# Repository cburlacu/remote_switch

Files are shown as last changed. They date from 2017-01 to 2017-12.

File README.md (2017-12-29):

# About

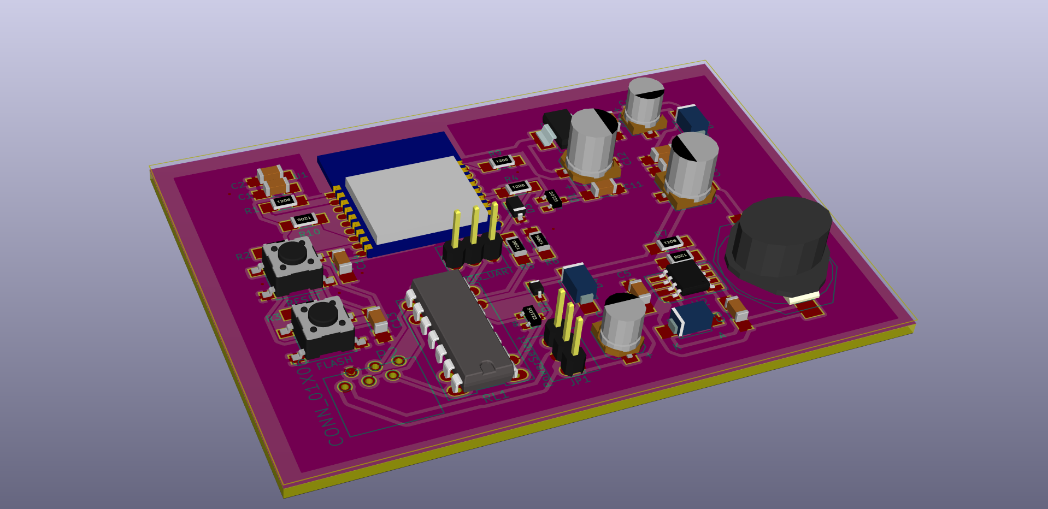
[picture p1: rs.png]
3D preview


If you need to press the power button of your laptop remotely you may use this :)

# Prerequisites
* Kicad:   https://kicad-pcb.org/download
* ESP SDK: https://github.com/pfalcon/esp-open-sdk.git
* uPython: https://github.com/micropython/micropython.git

# Hardware
```
https://esp8266.ru/wp-content/uploads/scheme-full-autoprog1-1024x586.jpg
https://github.com/esp8266/esp8266-wiki/wiki/Boot-Process
```
# TODO
- 10k resistor to ground for GPIO15/MTDO

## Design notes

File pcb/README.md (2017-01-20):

Using the footprint of ESP8266 from https://github.com/jdunmire/kicad-ESP8266.git

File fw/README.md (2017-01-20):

# Prerequisites
- esp toolchain
- micropython
- pip install adafruit-ampy 

The prerequisites can be found on tools subfolder.

## Building esp toolchain
git clone https://github.com/pfalcon/esp-open-sdk.git
Follow the instructions from https://github.com/pfalcon/esp-open-sdk/blob/master/README.md

## Building micropython
git clone https://github.com/micropython/micropython.git
The instruction can be found at https://github.com/micropython/micropython/blob/master/esp8266/README.md

# Updating firmware
1. Build the toolchain
2. Build the micropython for ESP8266
3. Flash to board

# Running a script at startup
By default, main.py will be executed if found on the board.

To put a script to board flash, ampy can be used:
```
ampy --port /dev/ttyXXX put script.py /main.py
```

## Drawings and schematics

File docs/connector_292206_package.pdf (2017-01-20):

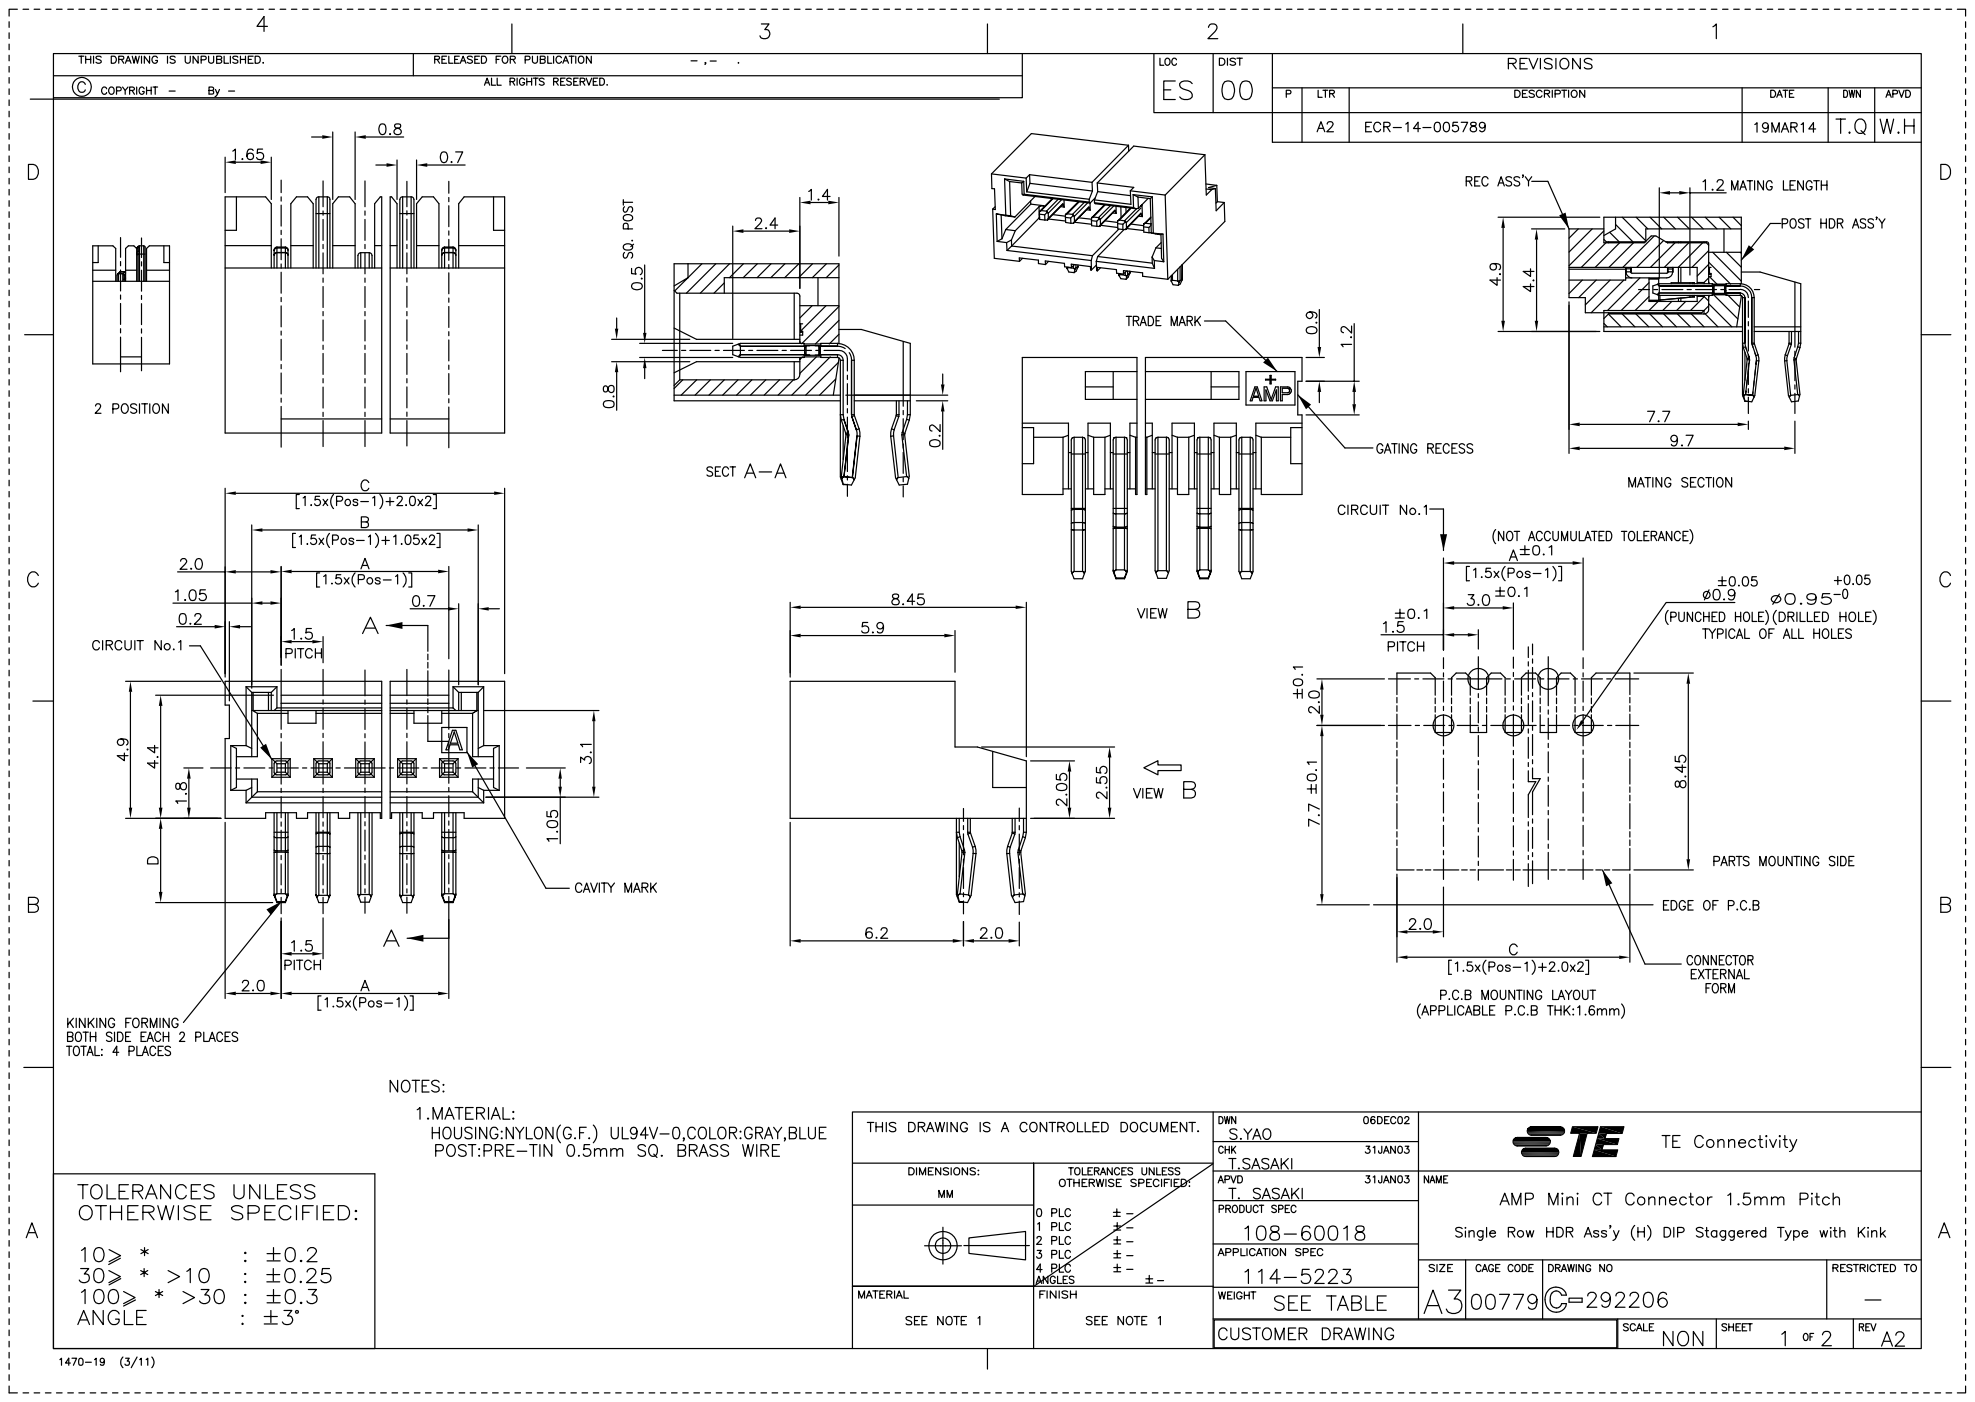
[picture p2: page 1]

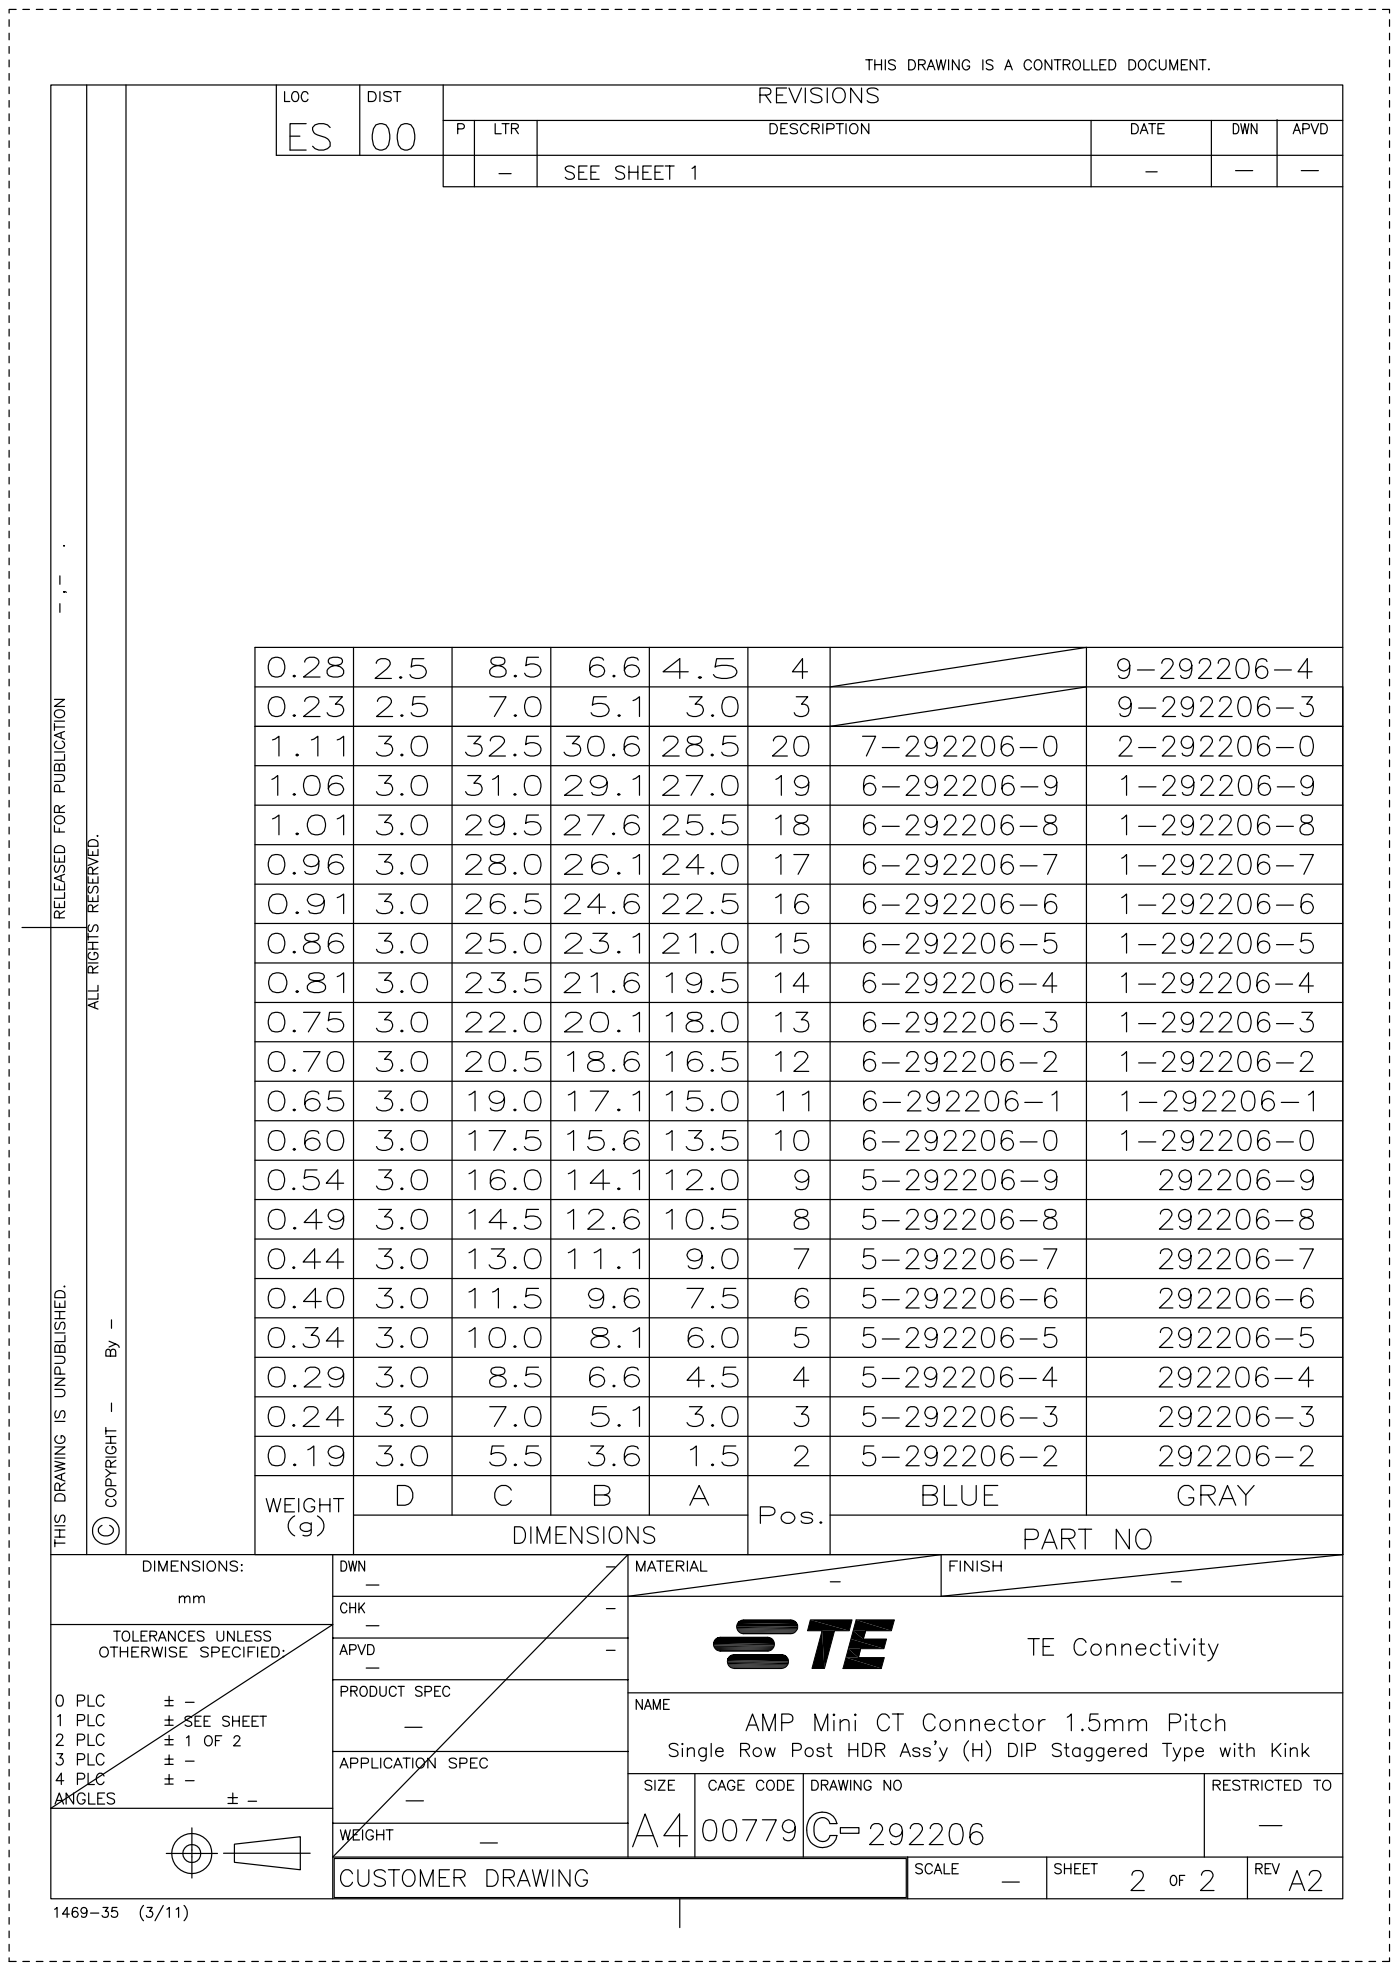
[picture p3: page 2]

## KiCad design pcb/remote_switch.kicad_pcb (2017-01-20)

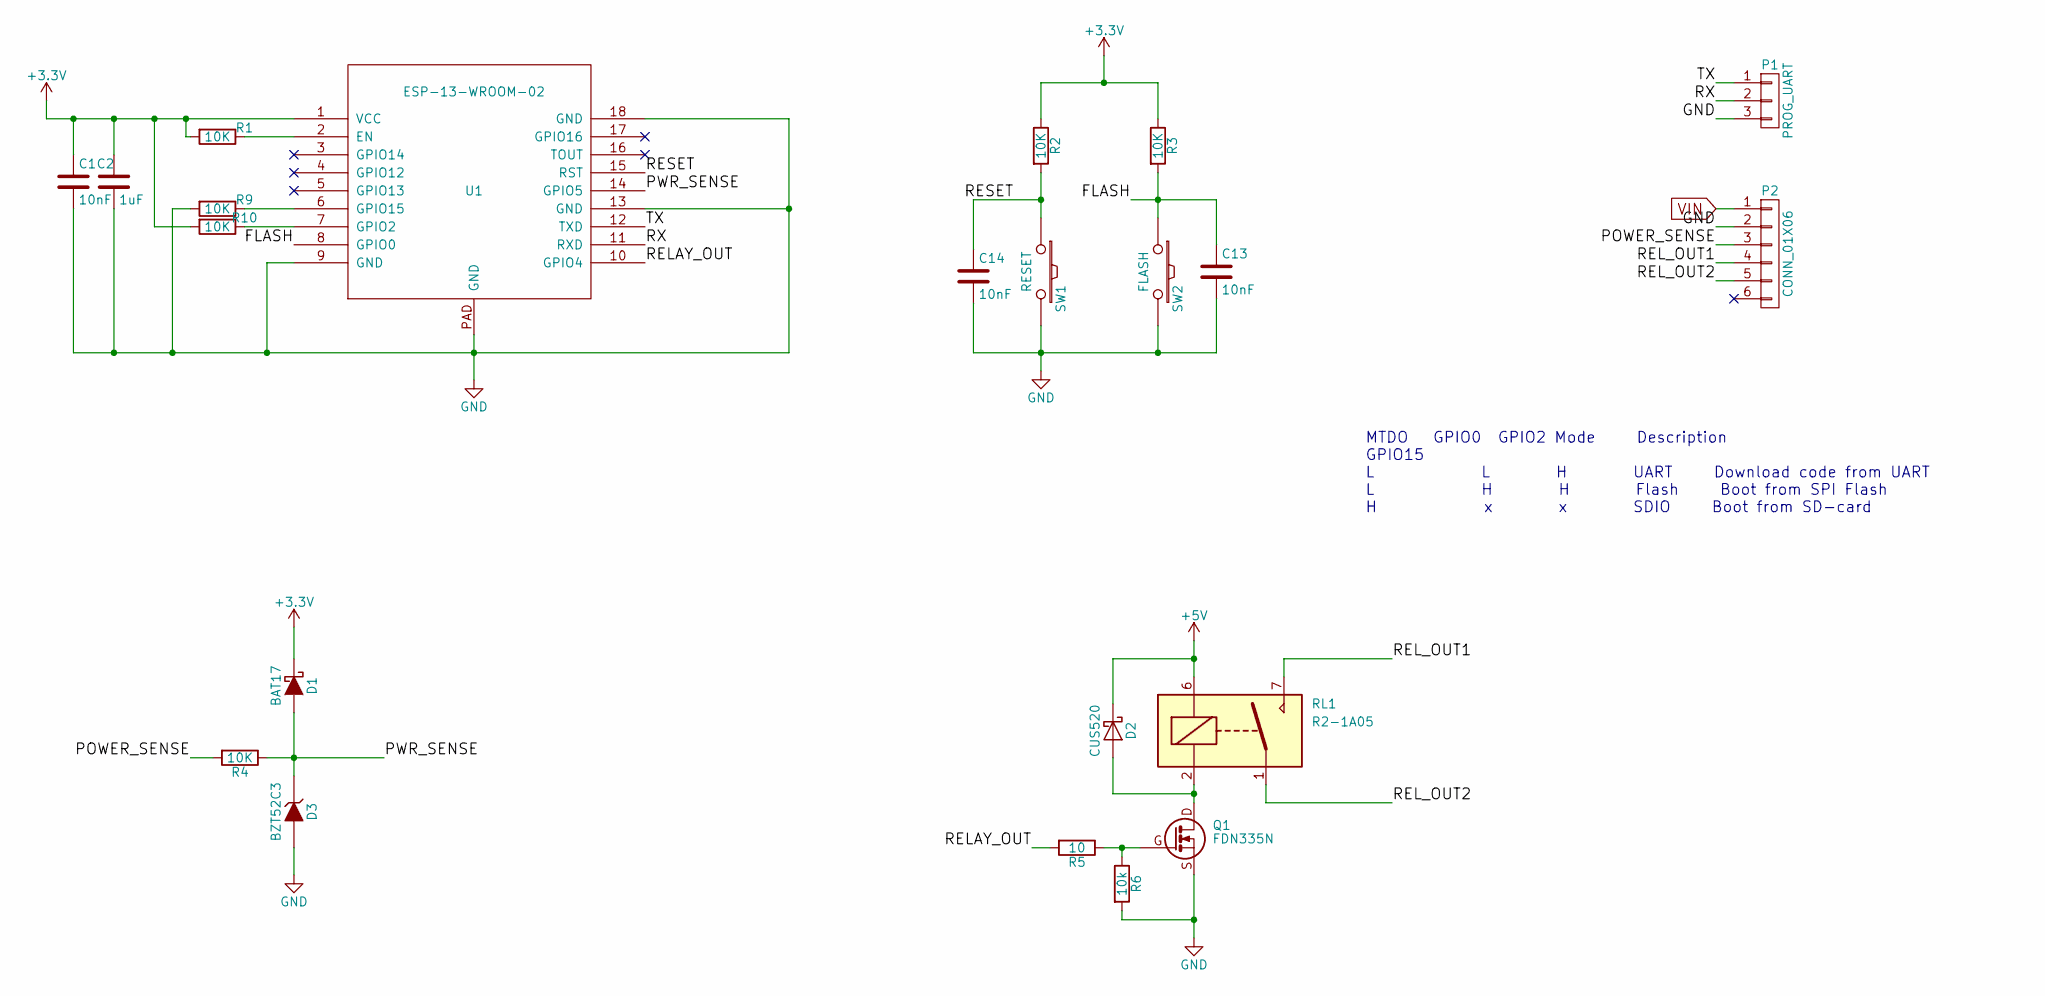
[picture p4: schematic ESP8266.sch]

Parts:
C1, C13, C14: 10nF; C_1206_HandSoldering
C2: 1uF; C_1206_HandSoldering
D1: BAT17; SOT-23
D2: CUS520; SOD-323_HandSoldering
D3: BZT52C3; SOD-123
P1: PROG_UART; PINHEAD1-3
P2: CONN_01X06; CON6_1X6_RHK_MINICT
Q1: FDN335N
R1, R2, R3, R4, R9, R10: 10K; R_1206_HandSoldering
R5: 10; R_1206_HandSoldering
R6: 10k; R_1206_HandSoldering
RL1: R2-1A05; R2-1A05_2
SW1: RESET; SW_SPST_B3S-1000
SW2: FLASH; SW_SPST_B3S-1000
U1: ESP-13-WROOM-02

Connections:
+3V3: C1.1, C2.1, D1.3 (K), R1.2, R2.1, R3.1, R10.2, U1.1 (VCC); also elsewhere on the board
+5V: D2.1 (K), RL1.6; also elsewhere on the board
/ESP8266/FLASH: C13.1, R3.2, SW2.1, U1.8 (GPIO0)
/ESP8266/POWER_SENSE: P2.3, R4.2
/ESP8266/PWR_SENSE: D1.1 (A), D3.1 (K), R4.1, U1.14 (GPIO5)
/ESP8266/RELAY_OUT: R5.2, U1.10 (GPIO4)
/ESP8266/REL_OUT1: P2.4, RL1.7
/ESP8266/REL_OUT2: P2.5, RL1.1
/ESP8266/RESET: C14.1, R2.2, SW1.1, U1.15 (RST)
/ESP8266/RX: P1.2, U1.11 (RXD)
/ESP8266/TX: P1.1, U1.12 (TXD)
GND: C1.2, C2.2, C13.2, C14.2, D3.2 (A), P1.3, P2.2, Q1.S, R6.2, R9.2, SW1.2, SW2.2, U1.9 (GND), U1.13 (GND), U1.18 (GND), U1.PAD (GND); also elsewhere on the board
unnamed: D2.2 (A), Q1.D, RL1.2
unnamed: Q1.G, R5.1, R6.1
unnamed: R1.1, U1.2 (EN)
unnamed: R9.1, U1.6 (GPIO15)
unnamed: R10.1, U1.7 (GPIO2)
VIN: P2.1; also elsewhere on the board

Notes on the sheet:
MTDO GPIO0 GPIO2 Mode Description GPIO15 L L H UART Download code from UART L H H Flash Boot from SPI Flash H x x SDIO Boot from SD-card

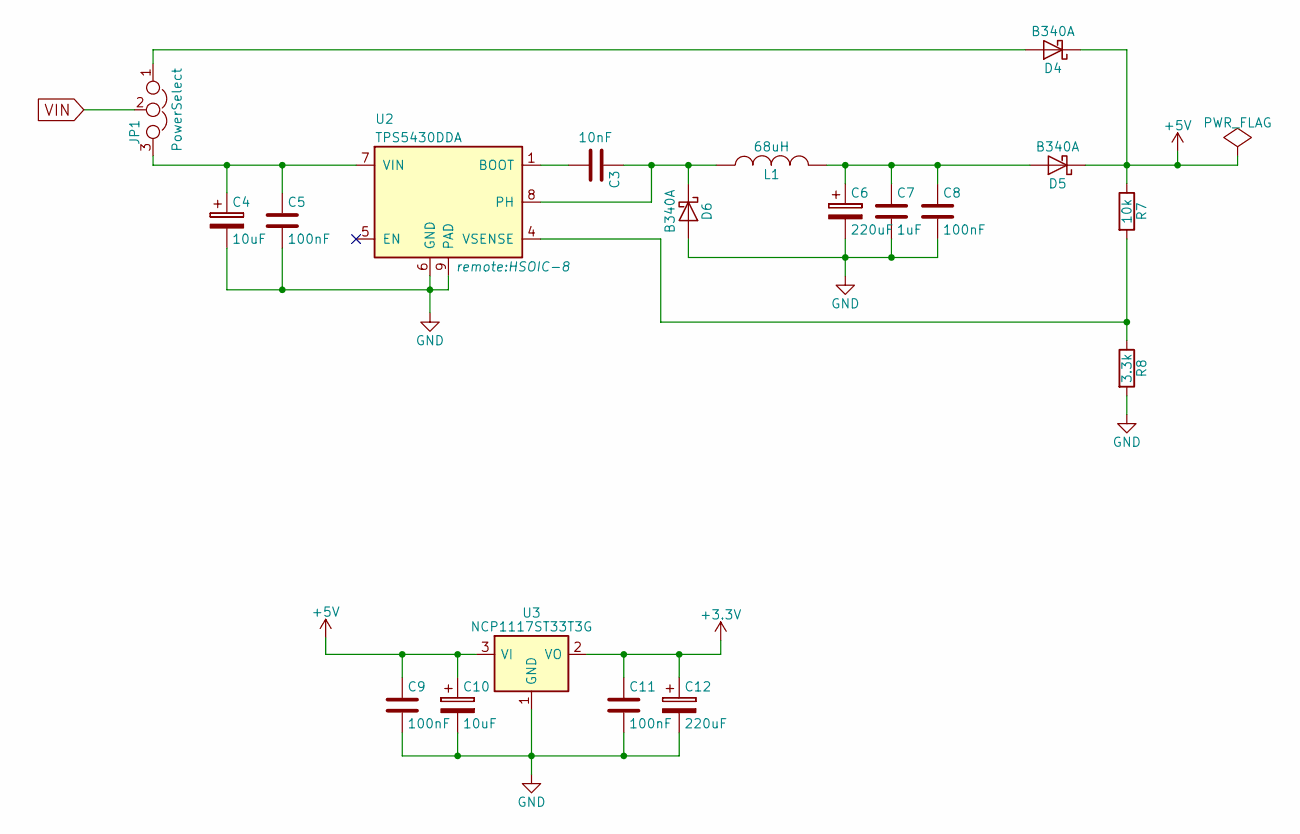
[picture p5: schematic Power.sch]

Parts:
C3: 10nF; C_1206_HandSoldering
C4, C10: 10uF; c_elec_5x5.8
C5, C8, C9, C11: 100nF; C_1206_HandSoldering
C6, C12: 220uF; c_elec_6.3x7.7
C7: 1uF; C_1206_HandSoldering
D4, D5, D6: B340A; SMA_Handsoldering
JP1: PowerSelect; PINHEAD1-3
L1: 68uH; DL50
R7: 10k; R_1206_HandSoldering
R8: 3.3k; R_1206_HandSoldering
U2: TPS5430DDA; HSOIC-8
U3: NCP1117ST33T3G; NCP1117-SOT32

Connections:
+3V3: C11.1, C12.1, U3.2 (VO); also elsewhere on the board
+5V: C9.1, C10.1, D4.1 (K), D5.1 (K), R7.1, U3.3 (VI); also elsewhere on the board
GND: C4.2, C5.2, C6.2, C7.2, C8.2, C9.2, C10.2, C11.2, C12.2, D6.2 (A), R8.2, U2.6 (GND), U2.9 (PAD), U3.1 (GND); also elsewhere on the board
unnamed: C3.1, D6.1 (K), L1.1, U2.8 (PH)
unnamed: C3.2, U2.1 (BOOT)
unnamed: C4.1, C5.1, JP1.3, U2.7 (VIN)
unnamed: C6.1, C7.1, C8.1, D5.2 (A), L1.2
unnamed: D4.2 (A), JP1.1
unnamed: R7.2, R8.1, U2.4 (VSENSE)
VIN: JP1.2; also elsewhere on the board

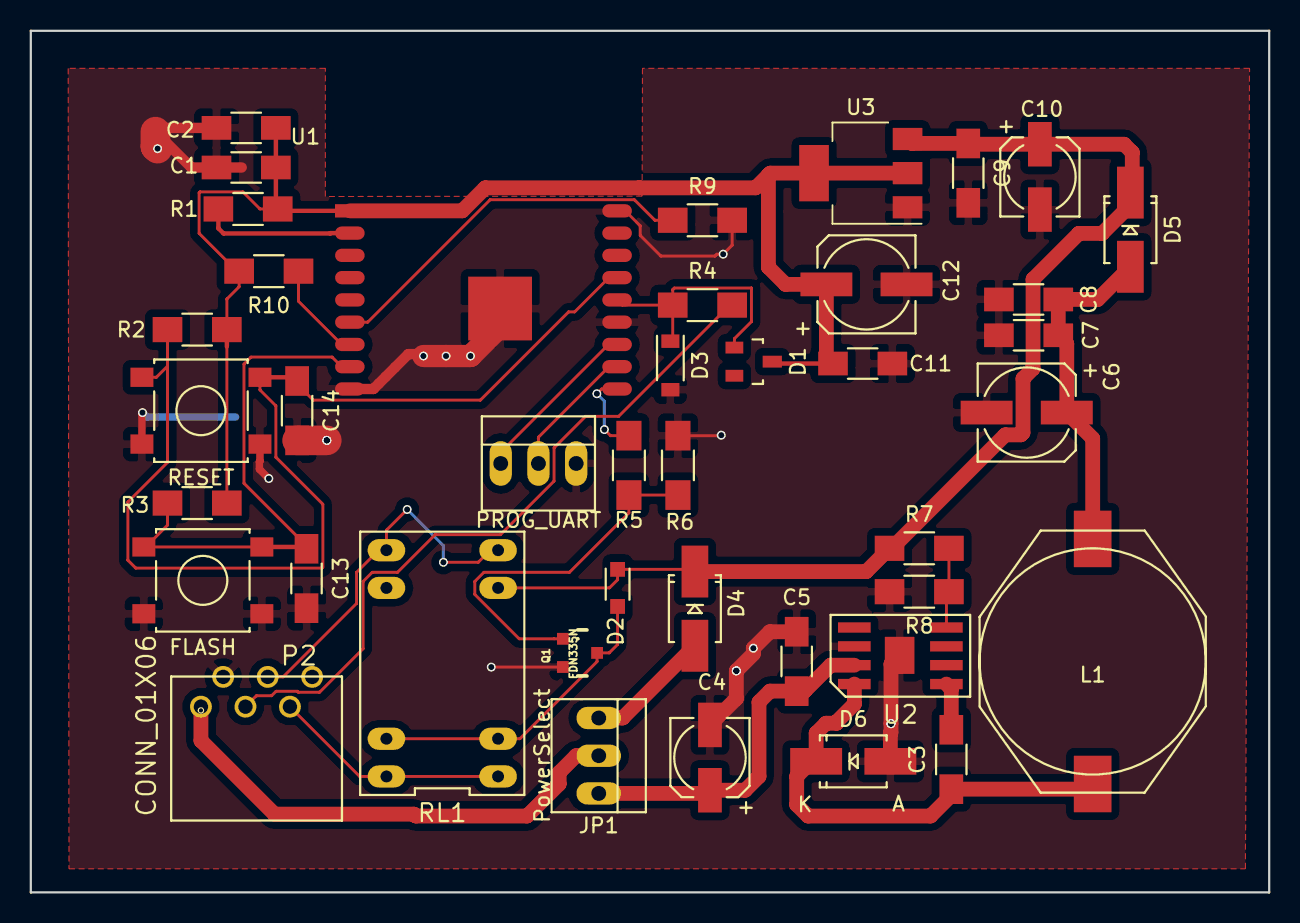
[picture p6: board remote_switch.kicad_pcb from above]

Board: 2 copper layers, 83.4 x 58.0 mm, 41 parts (0 on the bottom side), 24 nets.

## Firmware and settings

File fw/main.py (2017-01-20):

import network
import machine
import time
import socket

SSID        = 'CIPowerManager'
SSID_PASS   = ''
RECONNECT   = 30
CONNECTION_TIMEOUT = 5  # seconds
POWER_OFF_TIMER = 7
POWER_ON_TIMER = 3

LOCAL_ADDR = socket.getaddrinfo('0.0.0.0', 80)[0][-1]

RelayPin = machine.Pin(5, machine.Pin.OUT)
pwrStatPin = machine.Pin(15, machine.Pin.IN)
wlan = network.WLAN(network.STA_IF)


def setPin(pin, val):
    # time.sleep_ms(500)
    pin.value(val)
    # time.sleep_ms(500)
    while pin.value() != val:
        pin.value(val)
        # time.sleep_ms(500)


def pwrPush():
    setPin(RelayPin, 1)


def pwrRelease():
    setPin(RelayPin, 0)


def reset():
    RelayPin.value(1)
    time.sleep(2)
    RelayPin.value(0)


def waitFor(pin, val, period=1, msg=None):
    while pin.value() == val:
        time.sleep(period)
        if msg is not None:
            print(msg)


# TODO: read the power
def power():
    if pwrStatPin.value() == 1:
        pwrPush()
        # time.sleep(POWER_OFF_TIMER)  # keep the relay pushed at least 5 seconds to power down the machine
        print("Print power is ON, turning OFF")
        print("Press button")
        waitFor(pwrStatPin, 1, 1, "Waiting to power OFF...")
        pwrRelease()
        time.sleep(5)
        print("Release button")

    print("Print power is now OFF, turning ON")
    print("Press button")
    pwrPush()
    waitFor(pwrStatPin, 0, 1, "Waiting to power ON...")
    pwrRelease()
    time.sleep(1)
    print("Release button")


# start wlan conneciton
def wifi_connect(wifi, ssid, password):
    wifi.active(True)
    wifi.disconnect()
    wifi.connect(ssid, password)
    counter = 0
    while not wlan.isconnected():
        print("Still connecting...")
        time.sleep(1)
        counter = counter + 1
        if (counter % RECONNECT) == 0:  # try to reconnect once at 30 s
            wifi.connect(ssid, password)
    print("Network config:", wlan.ifconfig())


def getNextCommand(sock):
    print("Listening on", LOCAL_ADDR)
    validCommand = False
    command = ""
    while not validCommand:
        incoming, addr = sock.accept()
        incoming.settimeout(CONNECTION_TIMEOUT)
        while True:
            line = incoming.readline()
            if not line or line == b'\r\n':
                validCommand = False
                break
            else:
                command = line.lower().strip()
                validCommand = True
                break
    return command, incoming


# start "main"

if __name__ == '__main__':
    RelayPin.value(0)  # ensure that relay is open

    s = socket.socket()
    s.bind(LOCAL_ADDR)
    s.listen(1)

    while True:
        wifi_connect(wlan, SSID, SSID_PASS)
        # check again
        if wlan.isconnected():
            while True:  # main loop
                result = "Fail"
                comm, sock = getNextCommand(s)
                print("New command received ", comm)
                if comm == b'reset':
                    reset()
                    result = "OK"
                elif comm == b'power':
                    power()
                    result = "OK"
                else:
                    print("Unimplemented command", comm)
                print("The result is %s" % result)
                try:
                    sock.write(result + "\r\n")
                    sock.close()
                except OSError as ex:
                    print(ex)

        else:
            print("Still was not connected, do it again")
